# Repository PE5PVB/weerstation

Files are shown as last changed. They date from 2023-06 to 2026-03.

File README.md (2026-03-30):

# Weerstation



## Inleiding
Dit weerstation haalt alle weersinformatie voor jouw regio online op via een API van www.weerlive.nl. Jouw regio wordt bepaald aan de hand van de geografische coördinaten welke verkregen worden door de ingebouwde GPS ontvanger. Deze weersinformatie wordt elke 5 minuten vernieuwd. Mocht er een weerswaarschuwing gelden dan zal dit aangegeven worden met een rood knipperend uitroepteken. Druk op het uitroepteken om deze waarschuwing weer te geven. In dat zelfde scherm worden ook gedetecteerde bliksemontladingen weergegeven.
Voor radioamateurs is er ook een sectie ingericht waar relevante ruimteweersinformatie wordt weergegeven. Ook worden bandomstandigheden voor DX op korte golf en VHF getoond. Deze informatie wordt verkregen van hamqsl.com. De MUF informatie wordt verkregen van meteo.be. Deze gegevens worden respectievelijk elke 30 seconden en elke 20 seconden vernieuwd.
Tot slot is het weerstation uitgevoerd met een ingebouwde temperatuurmeter, luchtvochtigheidsmeter en een VOC meter. VOC geeft een indicatie van de luchtkwaliteit. VOC waardes onder 200 zijn prima, bij waardes boven 200 wordt ventilatie aanbevolen. Hoe hoger de waarde, hoe hoger de urgentie. Deze gegevens worden elke 5 seconden vernieuwd.
In een apart menu worden de GPS statistieken weergegeven. 

## Technische werking
Het hart van het weerstation is de ESP32 processor. Deze krachtige processor heeft ook een ingebouwd WiFi station. De software is geschreven op het welbekende Arduino platform. Software laden kan via de seriële poort J1. Hiervoor is wel een UART converter nodig. Om de ESP32 in de download stand te zetten dien je de spanning te verwijderen, de FLASH knop ingedrukt te houden en daarna de spanning terug te plaatsen. Hierna kun je de flash knop loslaten. Nu kun je de software laden.
Communicatie met de indoor temperatuur en luchtvochtigheid sensor loopt via een OneWire protocol. Dat wil zeggen dat alle data over één lijn loopt. Communicatie met de VOC en bliksemdetector loopt via de I2C databus. Tot slot is de GPS module gekoppeld middels een softwarematige seriële bus. 
Het Nextion display, dit is een HMI display wat dus zelfstandig werkt en dus ook eigen software heeft is aangesloten via de 2e seriële bus van de ESP32. Updates voor het Nextion scherm lopen via een SD kaart. Deze kan in de SD kaartlezer van het display worden geplaatst. Na het plaatsen dien je even kort de spanning los te halen. Daarna zal de update automatisch starten, de status wordt ook weergegeven op het display. Na de update kun je de SD kaart verwijderen en weer even kort de spanning los koppelen. Het display start daarna automatisch op met de nieuwe software.
De bliksemdetector analyseert ontvangen signalen op 500kHz met een bandbreedte van 33kHz. Aangezien dit vrij kritisch is, moet de capaciteit van de LC kring ingesteld worden voor een goede werking. Deze kan namelijk exemplarisch afwijken. In dit bouwproject wordt deze waarde automatisch gemeten en bepaald tijdens het opstarten.

## Handleiding
Dit weerstation is geheel afhankelijk van een werkende internet verbinding via Wi-Fi. Na het opstarten zal er eerst geprobeerd een verbinding te maken met het laatst verbonden Wi-Fi accesspoint. Mislukt dit, dan zal er een scherm verschijnen met de vraag om dit opnieuw te proberen. Druk je op het icoontje rechtsboven in het scherm, dan kun je eventueel de Wi-Fi opnieuw configureren.

### Wi-Fi opnieuw configureren
Je krijgt een QR code te zien. Ontgrendel je telefoon of tablet en scan de QR code. Je telefoon of tablet zal na een aantal seconden automatisch naar een configuratiepagina gaan waar je de Wi-Fi verbinding kunt configureren. Lukt dit niet, maak dan handmatig verbinding met het weerstation. De Wi-Fi-naam wordt onder de QR code getoond.

### API weerlive configureren
Zoals in de inleiding wordt geschreven maakt dit weerstation gebruik van de API van weerlive.nl. Het is dus belangrijk om een unieke code aan te vragen. Je kunt deze code gratis aanvragen door een account aan te maken op [https://weerlive.nl/api/toegang/](https://weerlive.nl/api/toegang/index.php). Let wel op, het aantal aanvragen per dag is voor de gratis accounts beperkt tot 300. Maak dus voor elk weerstation een unieke code aan. Je kunt de code invullen tijdens het configureren van Wi-Fi. 

## Hoofdscherm
In het hoofdscherm vind je de huidige weersinformatie, de weersverwachting en binnentemperatuur/luchtvochtigheid en VOC waarde. Daarnaast wordt boven in het scherm de plaats  getoond welke horen bij de getoonde weersinformatie. Mocht er voldoende GPS ontvangst zijn, of is NTP ingeschakeld, dan zal daar ook de actuele datum en tijd worden weergegeven én, indien Hamradio mode is geactiveerd, de 10 digit (Maidenhead) QTH locator.

## Hamradio scherm
In het Hamradio scherm worden de nodige data van de zonneactiviteit weergegeven, daarnaast worden de verwachte bandcondities voor de korte golf, de actuele Europese bandcondities voor VHF en de actuele MUF voor verschillende afstanden op de korte golf getoond. Dit laatste wordt als een ticker weergegeven onderin beeld.

## GPS scherm
Hier worden de actuele lengte- en breedtegraad, het aantal ontvangen satellieten, de actuele GPS UTC tijd, de berekende hoogte (niet nauwkeurig) en een foutindicatie weergegeven.

## Waarschuwingenscherm
In het waarschuwingenscherm worden actuele weerswaarschuwingen weergegeven met een ticker. Daarnaast wordt ook een lijst met laatst gedetecteerde bliksemontladingen getoond, hierbij wordt datum, tijd en relatieve afstand weergegeven.

## Configuratiescherm
De volgende gegevens kun je wijzigen in het configuratiescherm:

De eerste pagina bevat instellingen voor de bliksemdetector.

### Alleen bij weeralarm
Indien ingeschakeld worden er alleen blikseminslagen gedetecteerd indien er weer weerswaarschuwing van kracht is. Dit kan eventuele valse meldingen aanzienlijk reduceren.

### Bliksem gevoeligheid
Hiermee kun je de gevoeligheid van de bliksemdetector instellen. Een lagere waarde is gevoeliger, maar ook gevoeliger voor valse meldingen.

### Spike onderdrukking
Hiermee wordt de gevoeiligheid voor storingen ingesteld. Een lagere waarde is gevoeliger, maar ook gevoeliger voor valse meldingen.

### Binnen gebruik
Hiermee wordt de gevoeligheid van de detector geoptimaliseerd. Bij buiten gebruik zijn de omgevingsstoringen anders dan bij binnen gebruik. 

## Configuratie pagina 2:

### Beeper
Indien deze functie is ingeschakeld wordt er een pieptoon gegeven indien er een weerswaarschuwing geldt of indien er een bliksemontlading is gedetecteerd.

### Hamradio modus
Indien deze functie is ingeschakeld wordt het hamradio scherm toegankelijk en zal de QTH locatie bij voldoende GPS signaal worden getoond.

### Helderheid
Instelling voor helderheid van het scherm. Instelbaar tussen 20 en 100%.

### Km/u weergave
Geef de actuele windsnelheid in km/u. Indien uitgeschakeld is de weergave in m/s.

## Configuratie pagina 3:

### Auto locatie update
Indien ingeschakeld wordt de gedetecteerde GPS locatie gebruikt voor de weersinformatie. Indien het weerstation op een plek wordt geplaatst waar GPS ontvangst onmogelijk of zeer matig is, wordt aangeraden deze functie na één keer goede ontvangst uit te schakelen. Hierdoor wordt de informatie niet meer bijgewerkt. Dit is belangrijk omdat mogelijk foute data als gevolg van slechte ontvangst kan worden gebruikt. Indien dit is uitgeschakeld, zal de QTH locator ook niet meer worden weergegeven.

### Gebruik NTP
Vooral handig indien er slechte of geen GPS ontvangst mogelijk is. De datum en tijd wordt, indien geactiveerd, via het internet gesynchroniseerd.

### Indoor offset
Hiermee kun je de waarde van de temperatuursensor voor binnentemperatuur wijzigen. Dit is vooral van belang indien de temperatuursensor op de print wordt geplaatst. Eigen opgewekte warmte van het weerstation kunnen namelijk de gemeten temperatuur beïnvloeden. Het is aan te raden deze waarde te wijzigen wanneer het weerstation minimaal een uur is ingeschakeld.

### Auto dimmer
Indien ingeschakeld zal het display na 5 minuten automatisch gedimd worden. Dit kan ongedaan worden door het scherm aan te raken.

## Software
De software voor dit project is open source. Je kunt alle software en ook een 3d printbare behuizing vinden op mijn github pagina, https://github.com/PE5PVB/weerstation

Dit ontwerp is uitsluitend bedoeld voor zelfbouwtoepassing door hobbyisten. Commercieel gebruik en/of verkoop zonder toestemming van de auteur is nadrukkelijk niet toegestaan.

Aan de werking van software en/of hardware kunnen geen rechten worden ontleend. 
Bouw en gebruik is nadrukkelijk op eigen risico. 

De seriële poort van de ESP32 staat op de printplaat aangeduid met : G=Ground, T=TX, R=RX.

## Voeding

Dit weerstation wordt gevoed via een USB-C connector. Werkspanning is 5V. Het weerstation verbruikt maximaal 250mA. 

## Bouwinstructie

Ik heb dit project dusdanig ontworpen dat dit ook door niet ervaren zelfbouwers kan worden gebouwd. Het enige onderdeel waarmee je goed op moet letten is de ESP32 processor. Deze is namelijk  in SMD uitgevoerd. Begin altijd met het solderen van één aansluiting in een hoek. Je hebt dan namelijk de mogelijkheid om de ESP32 eventueel nog verder uit te lijnen. Weet je zeker dat de ESP32 goed is uitgelijnd, soldeer dan de andere hoek. Controleer nogmaals of de ESP32 goed is uitgelijnd en vlak op de printplaat ligt, daarna kun je de andere pootjes vast solderen.

Plaats nu vervolgens de overige onderdelen, begin bij laag (weerstanden) en eindig met hoog. Let bij het plaatsen van de transistor, de buzzer en elektrolytische condensatoren op de polariteit.

De bijgeleverde aansluitkabels van de DFRobot modules zijn vrij lang. Deze kun je naar eigen inzicht in te korten.
De aansluitingen van de kleuren van de draden van display en DFRobot modules staan aangegeven met de eerste letter van de kleur. (bv. R = Rood, B = Blauw, Z = zwart etc). Bij de bliksemdetector moet AUX worden aangesloten op de IRQ pin van het detector board. Dit is een losse pen! Bij de LED staat de L voor het lange pootje van de LED.

## Programmeren

Gebruik bij voorkeur de pre-compiled version van mijn github pagina. Start het programma FLASH.BAT en volg de instructies.
Indien je toch vanuit Arduino IDE wilt programmeren, controleer dan of alle benodigde libraries zijn geinstalleerd.

## Onderdelenlijst
Hieronder een overzicht van de benodigde componenten met componentennummer een aantal.

5x	C1, C2, C3, C5, C7		100n condensator (5mm pitch)

1x	C4				            100µF elektrolytische condensator (6.5mm diameter)

1x	C6				            10µF elektrolytische condensator (5.5mm diameter)

3x	R1, R2, R4			      10kΩ 0.25W weerstand

2x	R6, R7				        5.1kΩ 0.25W weerstand

1x	R3				            1kΩ 0.25W weerstand

1x	R5				            470Ω 0.25W weerstand

1x	D1				            3mm LED

1x	U1				            ESP32-WROOM-32UE

1x	U2				            DHT22 module

1x	U3				            LM1117T-3.3

1x	F1				            Zelfherstellende zekering PPTC Polyfuse 500mA (5mm pitch)

1x	SW1				            PCB Drukknop

1x	BZ1				            Actieve buzzer

1x	Q1				            BC547 transistor

1x	J1				            Pinheader, 3-pins (2.54mm pitch)

1x	J2				            ATGM336H GPS Module

1x	J3				            Pinheader, 4-pins (2.54mm pitch)

1x	J4				            DFRobot Gravity SGP40 module

1x	J5				            DFRobot Gravity Bliksem Afstandssensor

1x	J6				            USB-C 2.0 Female naar DIP Adapter

1x					              WiFi 2.4GHz antenne met uFL connector

1x					              Nextion Discovery 3.5” display

5x					              Bout M3 10mm

5x					              Moer M3

Alle bovenstaande onderdelen zijn verkrijgbaar bij Tinytronics.nl

## Trouble shooting

### Start niet goed op.
Mogelijk is de netadapter niet compatible. Ik heb dit project getest met een Raspberry Pi 4 voeding. Plaats eerst de USB kabel, daarna pas de adapter in de wandcontactdoos.

### Blijft tijdens het opstarten hangen op Bliksemdetector controle
Controleer of de AUX pin verbonden is met de IRQ pin van het detector board.

### Geeft geen actueel weerbericht, temperatuur blijft op 0 graden staan
Controleer API code op type fouten. Het is een hexadecimaal getal, dus gebruikte karakters zijn 0-9 en a-f.

### GPS module werkt niet
Controleer of de antenne connector niet tegen het batterijtje aan komt.

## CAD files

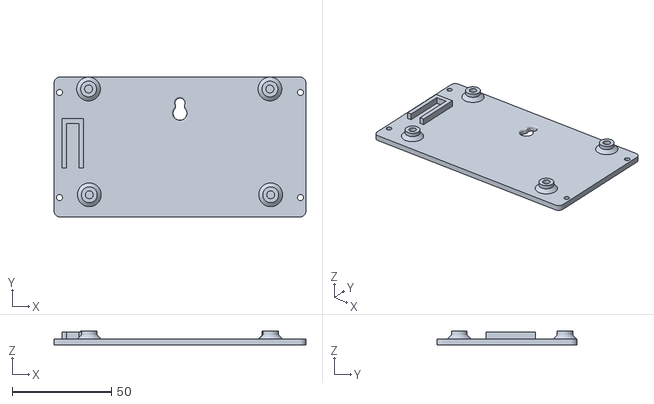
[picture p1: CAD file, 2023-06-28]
STL/mainboardback.stl
127.0 x 70.5 x 7.00

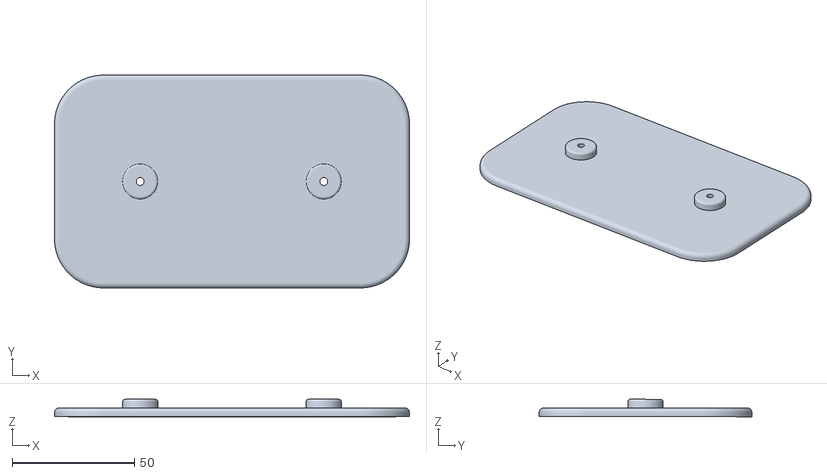
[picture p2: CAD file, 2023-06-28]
STL/foot.stl
145.0 x 86.9 x 7.17

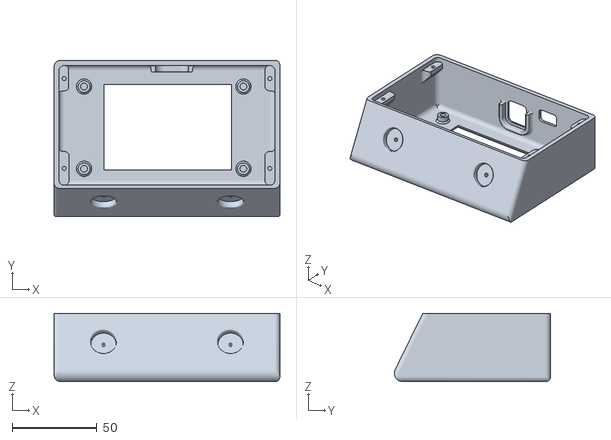
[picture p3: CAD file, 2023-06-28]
STL/frontcase.stl
133.4 x 92.3 x 40.3

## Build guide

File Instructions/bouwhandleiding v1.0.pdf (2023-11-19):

# Weerstation

### Bouwproject VRZA Radiokampweek 2023

## Inleiding

Dit weerstation haalt alle weersinformatie voor jouw regio online op via een API van www.weerlive.nl. Jouw regio wordt bepaald aan de hand van de geografische coördinaten welke verkregen worden door de ingebouwde GPS ontvanger. Deze weersinformatie wordt elke 5 minuten vernieuwd. Mocht er een weerswaarschuwing gelden dan zal dit aangegeven worden met een rood knipperend uitroepteken. Druk op het uitroepteken om deze waarschuwing weer te geven. In dat zelfde scherm worden ook gedetecteerde bliksemontladingen weergegeven.

Voor radioamateurs is er ook een sectie ingericht waar relevante ruimteweersinformatie wordt weergegeven. Ook worden bandomstandigheden voor DX op korte golf en VHF getoond. Deze informatie wordt verkregen van hamqsl.com. De MUF informatie wordt verkregen van meteo.be. Deze gegevens worden respectievelijk elke 30 seconden en elke 20 seconden vernieuwd.

Tot slot is het weerstation uitgevoerd met een ingebouwde temperatuurmeter, luchtvochtigheidsmeter en een VOC meter. VOC geeft een indicatie van de luchtkwaliteit. VOC waardes onder 200 zijn prima, bij waardes boven 200 wordt ventilatie aanbevolen. Hoe hoger de waarde, hoe hoger de urgentie. Deze gegevens worden elke 5 seconden vernieuwd.

In een apart menu worden de GPS statistieken weergegeven.

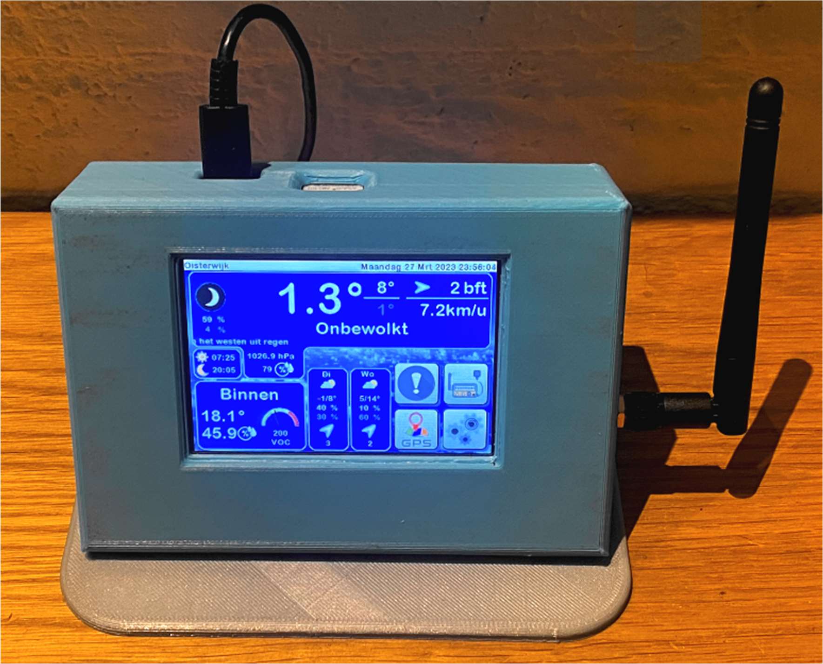
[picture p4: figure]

## Technische werking

Het hart van het weerstation is de ESP32 processor. Deze krachtige processor heeft ook een ingebouwd WiFi station. De software is geschreven op het welbekende Arduino platform. Software laden kan via de seriële poort J1. Hiervoor is wel een UART converter nodig. Om de ESP32 in de download stand te zetten dien je de spanning te verwijderen, de FLASH knop ingedrukt te houden en daarna de spanning terug te plaatsen. Hierna kun je de flash knop loslaten. Nu kun je de software laden.

Communicatie met de indoor temperatuur en luchtvochtigheid sensor loopt via een OneWire protocol. Dat wil zeggen dat alle data over één lijn loopt. Communicatie met de VOC en bliksemdetector loopt via de I2C databus. Tot slot is de GPS module gekoppeld middels een softwarematige seriële bus.

Het Nextion display, dit is een HMI display wat dus zelfstandig werkt en dus ook eigen software heeft is aangesloten via de 2e
seriële bus van de ESP32. Updates voor het Nextion scherm lopen via een SD kaart. Deze kan in de SD kaartlezer van het display worden geplaatst. Na het plaatsen dien je even kort de spanning los te halen. Daarna zal de update automatisch starten, de status wordt ook weergegeven op het display. Na de update kun je de SD kaart verwijderen en weer even kort de spanning los koppelen. Het display start daarna automatisch op met de nieuwe software.

De bliksemdetector analyseert ontvangen signalen op 500kHz met een bandbreedte van 33kHz. Aangezien dit vrij kritisch is, moet de capaciteit van de LC kring ingesteld worden voor een goede werking. Deze kan namelijk exemplarisch afwijken. In dit bouwproject wordt deze waarde automatisch gemeten en bepaald tijdens het opstarten.

## Handleiding

Dit weerstation is geheel afhankelijk van een werkende internet verbinding via Wi-Fi. Na het opstarten zal er eerst geprobeerd een verbinding te maken met het laatst verbonden Wi-Fi accesspoint. Mislukt dit, dan zal er een scherm verschijnen met de vraag om dit opnieuw te proberen. Druk je op het icoontje rechtsboven in het scherm, dan kun je eventueel de Wi-Fi opnieuw configureren.

Wi-Fi opnieuw configureren
Je krijgt een QR code te zien. Ontgrendel je telefoon of tablet en scan de QR code. Je telefoon of tablet zal na een aantal seconden automatisch naar een configuratiepagina gaan waar je de Wi-Fi verbinding kunt configureren. Lukt dit niet, maak dan handmatig verbinding met het weerstation. De Wi-Fi-naam wordt onder de QR code getoond.

API weerlive configureren
Zoals in de inleiding wordt geschreven maakt dit weerstation gebruik van de API van weerlive.nl. Het is dus belangrijk om een unieke code aan te vragen. Je kunt deze code gratis aanvragen door een account aan te maken op https://weerlive.nl/api/toegang/. Let wel op, het aantal aanvragen per dag is voor de gratis accounts beperkt tot 300. Maak dus voor elk weerstation een unieke code aan. Je kunt de code invullen tijdens het configureren van Wi-Fi.

Hoofdscherm
In het hoofdscherm vind je de huidige weersinformatie, de weersverwachting en binnentemperatuur/luchtvochtigheid en VOC waarde. Daarnaast wordt boven in het scherm de plaats getoond welke horen bij de getoonde weersinformatie. Mocht er voldoende GPS ontvangst zijn, of is NTP ingeschakeld, dan zal daar ook de actuele datum en tijd worden weergegeven én, indien Hamradio mode is geactiveerd, de 10 digit (Maidenhead) QTH locator.

Hamradio scherm
In het Hamradio scherm worden de nodige data van de zonneactiviteit weergegeven, daarnaast worden de verwachte bandcondities voor de korte golf, de actuele Europese bandcondities voor VHF en de actuele MUF voor verschillende afstanden op de korte golf getoond. Dit laatste wordt als een ticker weergegeven onderin beeld.

GPS scherm
Hier worden de actuele lengte- en breedtegraad, het aantal ontvangen satellieten, de actuele GPS UTC tijd, de berekende hoogte (niet nauwkeurig) en een foutindicatie weergegeven.

Waarschuwingenscherm
In het waarschuwingenscherm worden actuele weerswaarschuwingen weergegeven met een ticker. Daarnaast wordt ook een lijst met laatst gedetecteerde bliksemontladingen getoond, hierbij wordt datum, tijd en relatieve afstand weergegeven.

Configuratiescherm
De volgende gegevens kun je wijzigen in het configuratiescherm:

De eerste pagina bevat instellingen voor de bliksemdetector.

Alleen bij weeralarm
Indien ingeschakeld worden er alleen blikseminslagen gedetecteerd indien er weer weerswaarschuwing van kracht is. Dit kan eventuele valse meldingen aanzienlijk reduceren.

Bliksem gevoeligheid
Hiermee kun je de gevoeligheid van de bliksemdetector instellen. Een lagere waarde is gevoeliger, maar ook gevoeliger voor valse meldingen.

Spike onderdrukking
Hiermee wordt de gevoeiligheid voor storingen ingesteld. Een lagere waarde is gevoeliger, maar ook gevoeliger voor valse meldingen.

Binnen gebruik
Hiermee wordt de gevoeligheid van de detector geoptimaliseerd. Bij buiten gebruik zijn de omgevingsstoringen anders dan bij binnen gebruik.

Configuratie pagina 2:

Beeper
Indien deze functie is ingeschakeld wordt er een pieptoon gegeven indien er een weerswaarschuwing geldt of indien er een bliksemontlading is gedetecteerd.

Hamradio modus
Indien deze functie is ingeschakeld wordt het hamradio scherm toegankelijk en zal de QTH locatie bij voldoende GPS signaal worden getoond.

Helderheid
Instelling voor helderheid van het scherm. Instelbaar tussen 20 en 100%.

Km/u weergave
Geef de actuele windsnelheid in km/u. Indien uitgeschakeld is de weergave in m/s.

Configuratie pagina 3:

Auto locatie update
Indien ingeschakeld wordt de gedetecteerde GPS locatie gebruikt voor de weersinformatie. Indien het weerstation op een plek wordt geplaatst waar GPS ontvangst onmogelijk of zeer matig is, wordt aangeraden deze functie na één keer goede ontvangst uit te schakelen. Hierdoor wordt de informatie niet meer bijgewerkt. Dit is belangrijk omdat mogelijk foute data als gevolg van slechte ontvangst kan worden gebruikt. Indien dit is uitgeschakeld, zal de QTH locator ook niet meer worden weergegeven.

Gebruik NTP
Vooral handig indien er slechte of geen GPS ontvangst mogelijk is. De datum en tijd wordt, indien geactiveerd, via het internet gesynchroniseerd.

Indoor offset
Hiermee kun je de waarde van de temperatuursensor voor binnentemperatuur wijzigen. Dit is vooral van belang indien de temperatuursensor op de print wordt geplaatst. Eigen opgewekte warmte van het weerstation kunnen namelijk de gemeten temperatuur beïnvloeden. Het is aan te raden deze waarde te wijzigen wanneer het weerstation minimaal een uur is ingeschakeld.

Auto dimmer
Indien ingeschakeld zal het display na 5 minuten automatisch gedimd worden. Dit kan ongedaan worden door het scherm aan te raken.

## Software

De software voor dit project is open source. Je kunt alle software en ook een 3d printbare behuizing vinden op mijn github pagina, https://github.com/PE5PVB/weerstation (ontwerp behuizing, alle credits naar Eric-Jan de Boer)

Dit ontwerp is uitsluitend bedoeld voor zelfbouwtoepassing door hobbyisten. Commercieel gebruik en/of verkoop zonder toestemming van de auteur is nadrukkelijk niet toegestaan.

Aan de werking van software en/of hardware kunnen geen rechten worden ontleend. Bouw en gebruik is nadrukkelijk op eigen risico. De seriële poort van de ESP32 staat op de printplaat aangeduid met : G=Ground, T=TX, R=RX.

## Voeding

Dit weerstation wordt gevoed via een USB-C connector. Werkspanning is 5V. Het weerstation verbruikt maximaal 250mA.

## Bouwinstructie

Ik heb dit project dusdanig ontworpen dat dit ook door niet ervaren zelfbouwers kan worden gebouwd. Het enige onderdeel waarmee je goed op moet letten is de ESP32 processor. Deze is namelijk in SMD uitgevoerd. Begin altijd met het solderen van één aansluiting in een hoek. Je hebt dan namelijk de mogelijkheid om de ESP32 eventueel nog verder uit te lijnen. Weet je zeker dat de ESP32 goed is uitgelijnd, soldeer dan de andere hoek. Controleer nogmaals of de ESP32 goed is uitgelijnd en vlak op de printplaat ligt, daarna kun je de andere pootjes vast solderen.

Plaats nu vervolgens de overige onderdelen, begin bij laag (weerstanden) en eindig met hoog. Let bij het plaatsen van de transistor, de buzzer en elektrolytische condensatoren op de polariteit.

De bijgeleverde aansluitkabels van de DFRobot modules zijn vrij lang. Deze kun je naar eigen inzicht in te korten.

De aansluitingen van de kleuren van de draden van display en DFRobot modules staan aangegeven met de eerste letter van de kleur. (bv. R = Rood, B = Blauw, Z = zwart etc). Bij de bliksemdetector moet AUX worden aangesloten op de IRQ pin van het detector board. Dit is een losse pen! Bij de LED staat de L voor het lange pootje van de LED.

## Programmeren

Gebruik bij voorkeur de pre-compiled version van mijn github pagina. Start het programma FLASH.BAT en volg de instructies.

Indien je toch vanuit Arduino IDE wilt programmeren, controleer dan of alle benodigde libraries zijn geinstalleerd.

## Onderdelenlijst

Hieronder een overzicht van de benodigde componenten met componentennummer een aantal.

5x | C1, C2, C3, C5, C7 | 100n condensator (5mm pitch)
1x | C4 | 100µF elektrolytische condensator (6.5mm diameter)
1x | C6 | 10µF elektrolytische condensator (5.5mm diameter)
3x | R1, R2, R4 | 10kΩ 0.25W weerstand
2x | R6, R7 | 5.1kΩ 0.25W weerstand
1x | R3 | 1kΩ 0.25W weerstand
1x | R5 | 470Ω 0.25W weerstand
1x | D1 | 3mm LED
1x | U1 | ESP32-WROOM-32UE
1x | U2 | DHT22 module
1x | U3 | LM1117T-3.3
1x | F1 | Zelfherstellende zekering PPTC Polyfuse 500mA (5mm pitch)
1x | SW1 | PCB Drukknop
1x | BZ1 | Actieve buzzer
1x | Q1 | BC547 transistor
1x | J1 | Pinheader, 3-pins (2.54mm pitch)
1x | J2 | ATGM336H GPS Module
1x | J3 | Pinheader, 4-pins (2.54mm pitch)
1x | J4 | DFRobot Gravity SGP40 module
1x | J5 | DFRobot Gravity Bliksem Afstandssensor
1x | J6 | USB-C 2.0 Female naar DIP Adapter
1x | | WiFi 2.4GHz antenne met uFL connector
1x | | Nextion Discovery 3.5” display
5x | | Bout M3 10mm
5x | | Moer M3

Alle bovenstaande onderdelen zijn verkrijgbaar bij Tinytronics.nl

## Trouble shooting

Start niet goed op.
Mogelijk is de netadapter niet compatible. Ik heb dit project getest met een Raspberry Pi 4 voeding. Plaats eerst de USB kabel, daarna pas de adapter in de wandcontactdoos.

### Blijft tijdens het opstarten hangen op Bliksemdetector controle

Controleer of de AUX pin verbonden is met de IRQ pin van het detector board.

### Geeft geen actueel weerbericht, temperatuur blijft op 0 graden staan

Controleer API code op type fouten. Het is een hexadecimaal getal, dus gebruikte karakters zijn 0-9 en a-f.

### GPS module werkt niet

Controleer of de antenne connector niet tegen het batterijtje aan komt.

## Schema

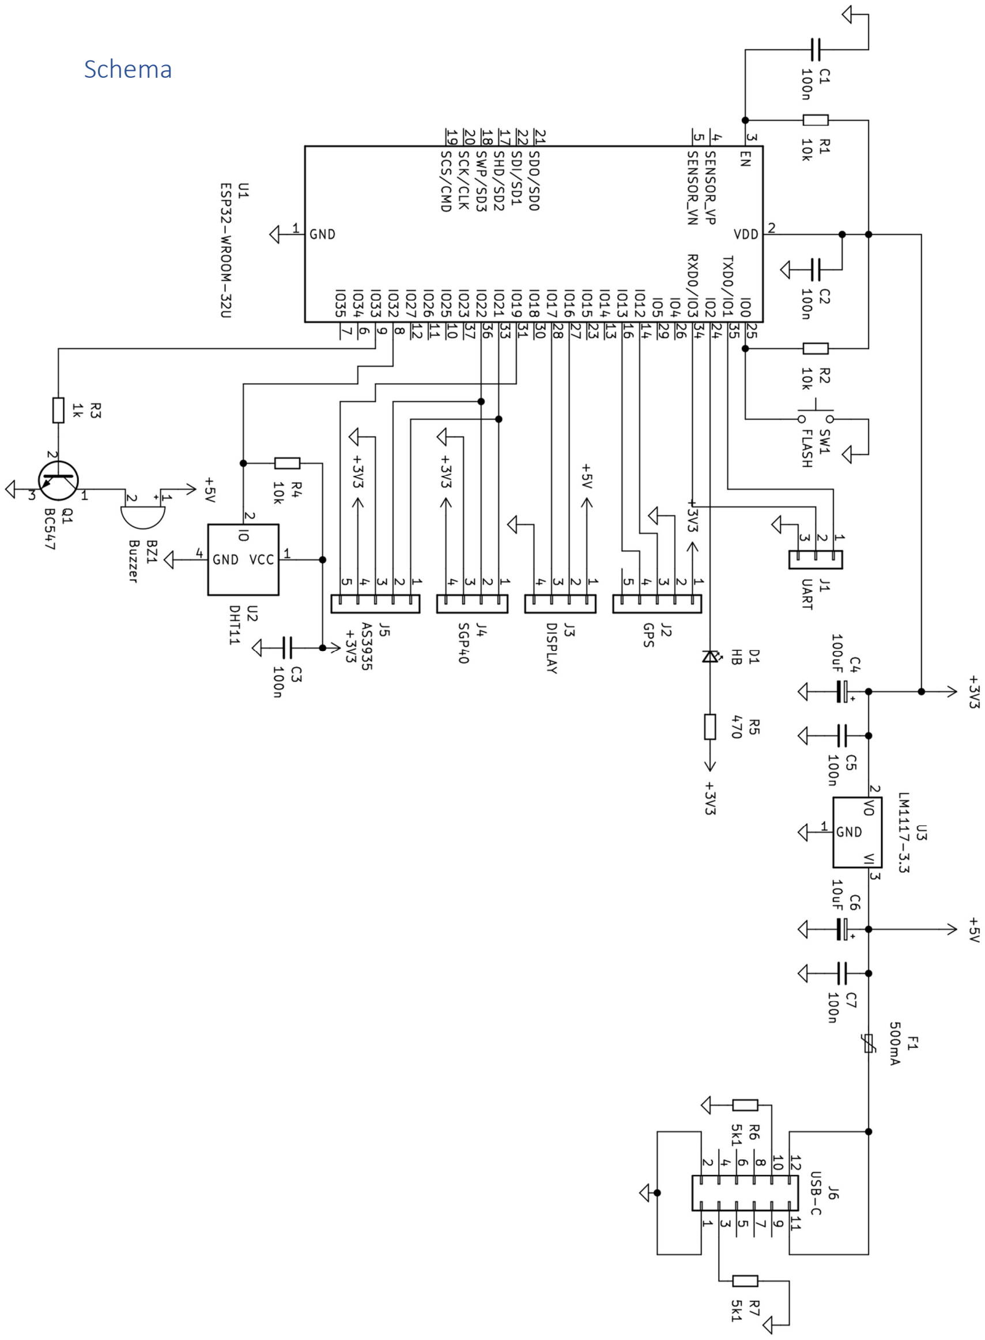
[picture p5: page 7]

## Componentenopstelling

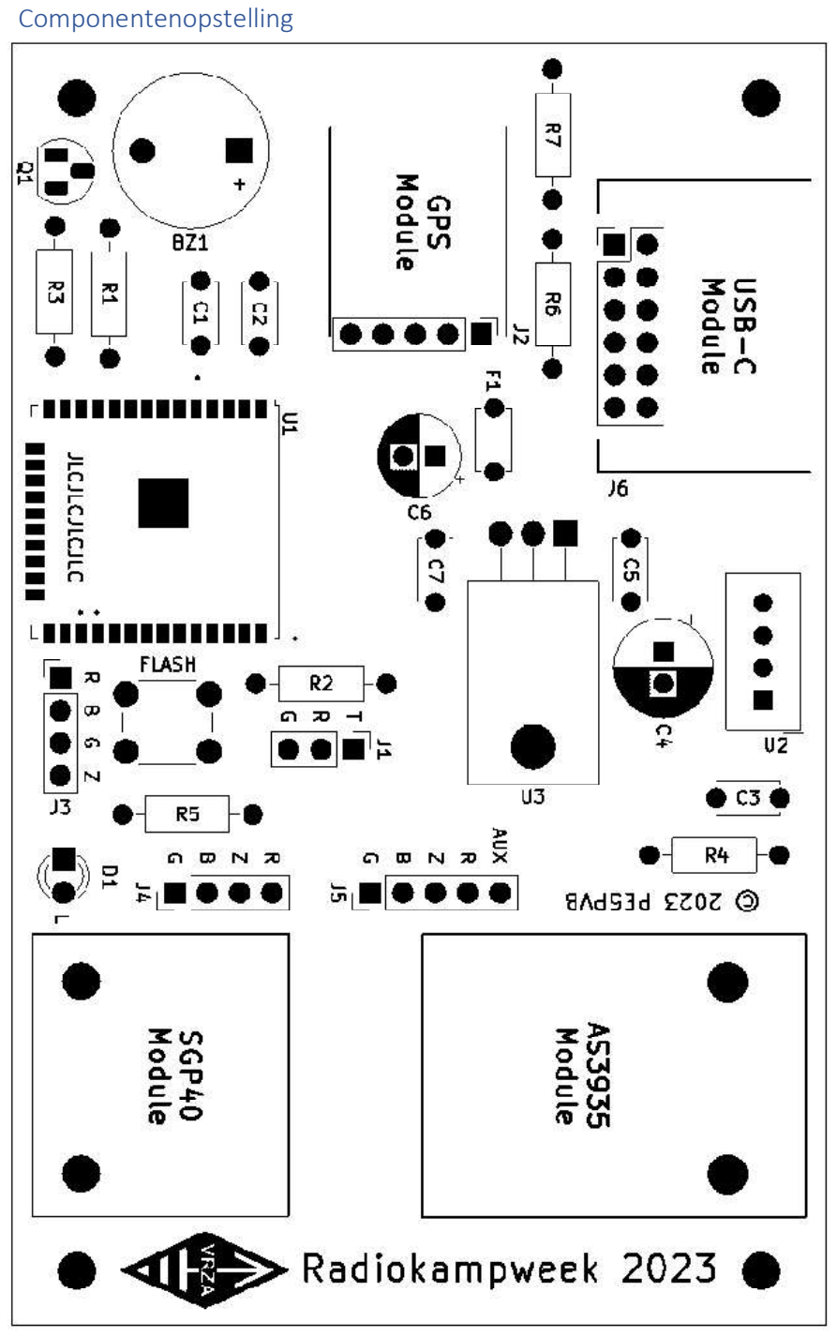
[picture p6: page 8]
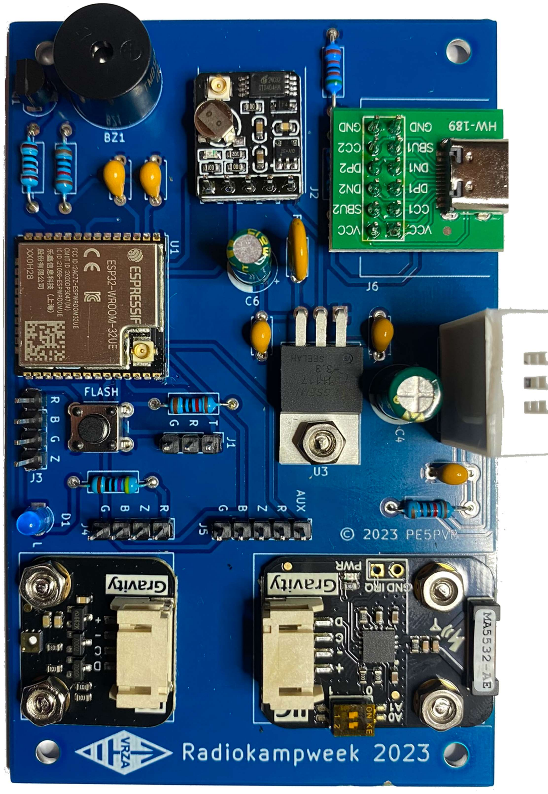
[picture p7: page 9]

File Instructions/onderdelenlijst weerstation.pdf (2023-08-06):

## De onderdelenlijst

Sommige onderdelen zijn lastig te vinden. Echter Tinytronics uit Eindhoven heeft vrijwel alles op voorraad !

Tinytronics levert desgewenst je ook een printplaat waarop reeds de ESP32 gesoldeerd is. Dat scheelt een boel priegelwerk. Om je het nog gemakkelijker te maken, kun je bij hen ook een volledige bouwkit met alle onderdelen bestellen. ( exclusief Kastje en USB voedingsadapter)

Zie verder op :
https://www.tinytronics.nl/shop/index.php?route=product/search&search=weerstation

Wil je het allemaal zelf doen, dan volgt hieronder de onderdelenlijst

Hierbij een overzicht van de benodigde componenten met componentennummer een aantal.

5x | C1, C2, C3, C5, C7 | 100n condensator (5mm pitch)
1x | C4 | 100µF elektrolytische condensator (6.5mm diameter)
1x | C6 | 10µF elektrolytische condensator (5.5mm diameter)
3x | R1, R2, R4 | 10kΩ 0.25W weerstand
2x | R6, R7 | 5.1kΩ 0.25W weerstand
1x | R3 | 1kΩ 0.25W weerstand
1x | R5 | 470Ω 0.25W weerstand
1x | D1 | 3mm LED
1x | U1 | ESP32-WROOM-32UE
1x | U2 | DHT22 module
1x | U3 | LM1117T-3.3
1x | F1 | Zelfherstellende zekering PPTC Polyfuse 500mA (5mm pitch)
1x | SW1 | PCB Drukknop
1x | BZ1 | Actieve buzzer
1x | Q1 | BC547 transistor
1x | J1 | Pinheader, 3-pins (2.54mm pitch)
1x | J2 | ATGM336H GPS Module
1x | J3 | Pinheader, 4-pins (2.54mm pitch)
1x | J4 | DFRobot Gravity SGP40 module
1x | J5 | DFRobot Gravity Bliksem Afstandssensor
1x | J6 | USB-C 2.0 Female naar DIP Adapter
1x | | WiFi 2.4GHz antenne met uFL connector
1x | | Nextion Discovery 3.5” display
5x | | Bout M3 10mm
5x | | Moer M3

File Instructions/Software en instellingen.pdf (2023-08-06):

## Software en instellingen

De software voor dit project is open source. Je kunt alle software en ook een 3d printbare behuizing ook vinden op de Github pagina van PE5PVB, https://github.com/PE5PVB/weerstation
(voor ontwerp behuizing, alle credits naar Eric-Jan de Boer).

Aan de werking van software en/of hardware kunnen geen rechten worden ontleend. Bouw en gebruik is nadrukkelijk op eigen risico.
Alle benodigde files vindt je in de ZIP file in de downloadmap, Software bijlage.
Pak de ZIP-file uit en schrijf alles naar een aparte map op je PC of laptop.

### Update Nextion grafisch display

Het Nextion display, dit is een Human Machine Interface (HMI) display wat zelfstandig werkt en dus ook eigen software heeft, en is aangesloten via de 2e
seriële bus van de ESP32. Updates voor het Nextion scherm lopen via een SD kaart. Gebruik een goed merk 16 Gb Micro SD kaartje

Op het SD kaartje dient eerst nog 1 bestand te worden gezet :
- weerstation.tft

De SD kaart kan dan in de SD kaartlezer van het display worden geplaatst.
Na het plaatsen dien je de spanning aan te sluiten. Daarna zal de update automatisch starten, de status wordt ook weergegeven op het display.
Na de update kun je de spanning uit te schakelen en de SD kaart verwijderen.
Na het weer inschakelen tart het display dan automatisch op met de nieuwe software.

## Het programmeren van de ESP32

Gebruik bij voorkeur het pre-compiled version FLASH.BAT bestand in de Software bijlage. Dit is de snelste en de meest gemakkelijke manier om alles te laden.

Software laden kan via de seriële poort J1. Hiervoor is wel een UART converter nodig.

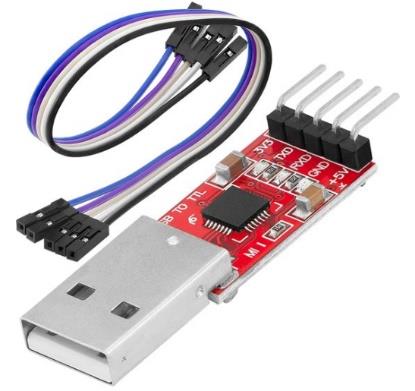
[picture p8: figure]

Stop de UART convertor in een USB poort op je laptop of PC en controleer welke COM-poort er wordt toegevoegd !
De seriële poort van de ESP32 staat op de printplaat aangeduid met : G=Ground, T=TX, R=RX. Verbind TX van de print met RX van de UART convertor en RX van de print met TX. G met Ground.

Start het FLASH.BAT bestand via je PC of Laptop op

Om de ESP32 in de download stand te zetten dien je de spanning te verwijderen, de FLASH knop op de print ingedrukt te houden en daarna de spanning terug te plaatsen op de USB ingang.
Hierna kun je de flash knop loslaten. De ESP32 komt hiermede in de laad-modus.

Nu kun je de software laden. Druk op <Enter> in je PC of Laptop en volg de aanwijzingen op het scherm om het laden te starten.

Opmerking :
Indien je toch vanuit Arduino IDE wilt programmeren, controleer dan of alle benodigde libraries zijn geïnstalleerd en gebruik het weerstation.ino bestand.

Na het laden verwijder je de voedingspanning en de aansluitingen van de UART.
Daarna kun je de voedingspanning weer aanbrengen.

### Let op :

Bij de bliksemdetector moet AUX worden aangesloten op de IRQ pin van het detector board met een los draadje. Vergeet dat niet !!

## Opstarten Weerstation

Het weerstation is geheel afhankelijk van een goed werkende internet verbinding via Wi-Fi.
Na het opstarten zal er eerst geprobeerd een verbinding te maken met het laatst verbonden Wi-Fi accesspoint. Mislukt dit, dan zal er een scherm verschijnen met de vraag om dit opnieuw te proberen. Druk je op het icoontje rechtsboven in het scherm, dan kun je de Wi-Fi opnieuw configureren. ( Opmerking : dit zal dus ook de eerste keer het geval zijn)

Wi-Fi opnieuw configureren
Je krijgt een QR code te zien. Ontgrendel je telefoon of tablet en scan de QR code. Je telefoon of tablet zal na een aantal seconden automatisch naar een configuratiepagina gaan waar je de Wi-Fi verbinding kunt configureren. Lukt dit niet, maak dan handmatig verbinding met het weerstation. De Wi-Fi-naam wordt onder de QR code getoond.
Bij het instellen heb je nu ook je API code nodig. Zorg dus dat je die bij de hand hebt.

Bij een goed gevonden Wifi signaal zal het weerstation nu opstarten.
Heb je een goede GPS dekking dan zal je huidige locatie worden getoond en de bijbehorende QTH locator gegevens, Indien je geen of een te zwak GPS aanwezig is, schakel dan de NTP instelling in het configuratiescherm in, om de juiste datum en tijd te krijgen.

### Trouble Shooting

Start niet goed op.
Mogelijk is de netadapter niet compatible. Ik heb dit project getest met een Raspberry Pi 4 voeding. Plaats eerst de USB kabel, daarna pas de adapter in de wandcontactdoos.

### Blijft tijdens het opstarten hangen op Bliksemdetector controle

Controleer of de AUX pin verbonden is met de IRQ pin van het detector board.

### Geeft geen actueel weerbericht, temperatuur blijft op 0 graden staan

Controleer API code op type fouten. Het is een hexadecimaal getal, dus gebruikte karakters zijn 0-9 en a-f.

### GPS module werkt niet

Controleer of de antenne connector niet tegen het batterijtje aan komt.

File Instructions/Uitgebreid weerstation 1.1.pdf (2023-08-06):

# Uitgebreid weerstation PE5PVB

Door Cor Struyk PA0GTB

### Inleiding

Soms valt je oog op een mooi project waarvan je gelijk weet, dat wil ik ook gaan maken. Dat gebeurde ook toen ik onlangs terugkwam van vakantie en een heel mooi artikel vond van Sjef Verhoeven PE5PVB. Het betrof een uitgebreid weerstation dat hij als bouwproject voor de VRZA-kampweek 2023 had gemaakt.

Via Github vond ik de Gerberfiles voor de printplaat, en toen ik hierover mijn vaste bouwmaatje Bert PA1BM, benaderde waren we het er gelijk over eens: dit werd ons volgende project.

Onlangs hebben we het project succesvol afgerond en heb ik Sjef PE5PVB benaderd of ik dit mooie project apart mocht beschrijven. Sjef gaf mij toestemming en info verstrekt zodat ik dit project hier nu nader beschrijf.

### Algemeen

Dit weerstation haalt alle weersinformatie voor jouw regio online op via een API van www.weerlive.nl. Jouw regio wordt bepaald aan de hand van de geografische coördinaten door de ingebouwde GPS-ontvanger. Deze weersinformatie wordt elke vijf minuten vernieuwd.

Mocht er een weerswaarschuwing gelden zie je dat meteen aan het rode uitroepteken. Druk op dit uitroepteken om deze waarschuwing weer te geven. In dat zelfde scherm worden ook gedetecteerde bliksemontladingen weergegeven.

Voor radioamateurs is er ook een sectie ingericht met relevante propagatieinformatie. Ook worden bandomstandigheden voor DX op korte golf en VHF getoond. Deze informatie komt van hamqsl.com. De MUF-informatie wordt verkregen van meteo.be. Deze gegevens worden respectievelijk elke 30 seconden en elke 20 seconden vernieuwd.

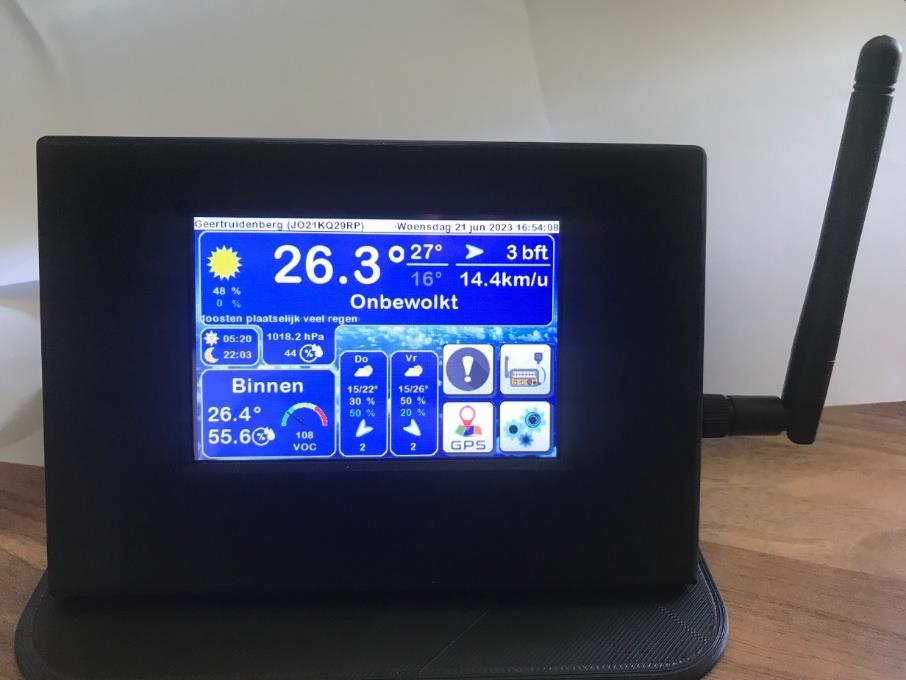
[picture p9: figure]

Het weerstation is voorzien van een aantal sensoren zodat je in een oogopslag kunt zien hoe het er binnen en buiten bijstaat. Te onderkennen zijn:

- Actuele weerinformatie van jou regio via Weeronline.nl
- Regionale KNMI weeralarm situatie voor jou regio
- Weersverwachting komende dagen
- Indoor temperatuur en vochtigheidssensor
- Windrichting en snelheden
- VOC-sensor (Luchtkwaliteit)
- GPS-sensor met antenne ( bepaalt je plaats en QTH locator)
- NTP datum en tijd (optioneel in te schakelen)
- Bliksemdetector

### Ham Radio mode

Naast de actuele indoor- en outdoor weerindicatie is het ook mogelijk om een zogenaamde. Hamradio mode in te schakelen. Hierbij wordt je 10 digit (Maidenhead) QTH locator getoond. In het Hamradioscherm worden de nodige data van de zonneactiviteit weergegeven. Daarnaast worden de verwachte bandcondities voor de korte golf, de actuele Europese bandcondities voor VHF en de actuele MUF voor verschillende afstanden op de korte golf getoond.

### De gebruikte techniek

Het hart van het weerstation is de ESP32 processor. Deze krachtige processor heeft ook een ingebouwd WiFi-station. De software is geschreven op het welbekende Arduino-platform. Software laden kan via de seriële poort J1. Hiervoor is wel een UART converter nodig.

Om de ESP32 in de downloadstand te zetten moet je de spanning verwijderen, de FLASH knop ingedrukt houden en daarna de spanning terugplaatsen. Hierna kun je de flash-knop loslaten. Nu kun je de software laden.

Communicatie met de indoor temperatuur en luchtvochtigheidssensor loopt via een OneWire-protocol. Dat wil zeggen dat alle data over één lijn loopt. Communicatie met de VOC en bliksemdetector loopt via de I2C databus. Tot slot is de GPS-module gekoppeld middels een softwarematige seriële bus.

Er wordt gebruikgemaakt van een Nextion grafisch display met touch screenbediening. Voorafgaand aan het programmeren van de ESP32 moet het display eerst geüpdatet worden via een SD-kaart. Zie hiervoor de softwarehandleiding waarin beschreven staat hoe dit te doen.

De bliksemdetector analyseert ontvangen signalen op 500kHz met een bandbreedte van 33kHz. Aangezien dit vrij kritisch is, moet de capaciteit van de LC-kring ingesteld worden voor een goede werking. Deze kan namelijk exemplarisch afwijken. In dit bouwproject wordt deze waarde automatisch gemeten en bepaald tijdens het opstarten.

### Internetverbinding

Dit weerstation is geheel afhankelijk van een werkende internetverbinding via Wi-Fi. Na het opstarten probeert het apparaat een verbinding te maken met het laatst verbonden Wi-Fi accesspoint. Mislukt dit, dan zal er een scherm verschijnen met de vraag om dit opnieuw te proberen. Druk je op het icoontje rechtsboven in het scherm, dan kun je de Wi-Fi opnieuw configureren.

Wi-Fi opnieuw configureren

Je krijgt een QR-code te zien. Ontgrendel je telefoon of tablet en scan de QR-code. Je telefoon of tablet zal na een aantal seconden automatisch naar een configuratiepagina gaan waar je de Wifi verbinding kunt configureren.

Lukt dit niet, maak dan handmatig verbinding met het weerstation. De Wi-Finaam wordt onder de QR-code getoond. Zie voor meer details de softwarehandleiding.

### API-code Weerlive.nl

Dit weerstation maakt gebruik van de API van weerlive.nl. Het is dus belangrijk om een unieke code aan te vragen. Je kunt deze gratis aanvragen door een account aan te maken op https://weerlive.nl/api/toegang/. Maak voor elk weerstation een unieke code aan. Je kunt de API-code invullen tijdens het configureren van Wi-Fi.

### Het schema

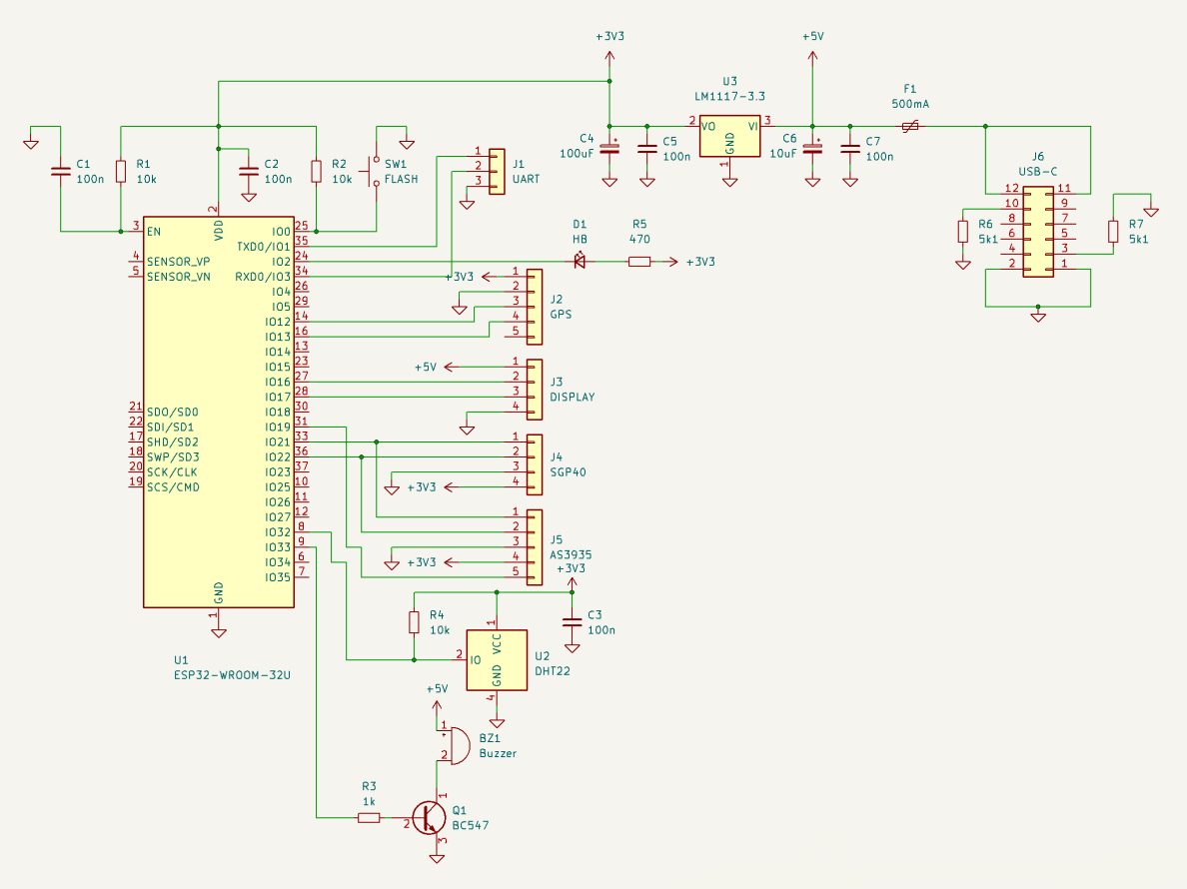
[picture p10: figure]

### De bouwinstructie

Sjef heeft dit project dusdanig ontworpen dat ook niet- ervaren zelfbouwers dit kunnen maken. Het enige onderdeel waarmee je goed moet opletten is de ESP32-processor. Deze is namelijk in SMD uitgevoerd.

Begin altijd met het solderen van één aansluiting in een hoek. Je hebt dan namelijk de mogelijkheid om de ESP32 eventueel nog verder uit te lijnen. Weet je zeker dat de ESP32 goed is uitgelijnd, soldeer dan de andere hoek. Controleer nogmaals of de ESP32 goed is uitgelijnd en vlak op de printplaat ligt. Daarna kun je de andere pootjes vastsolderen.

Plaats nu vervolgens de overige onderdelen, begin bij laag (weerstanden) en eindig met hoog. Let bij het plaatsen van de transistor, de buzzer en elektrolytische condensatoren op de polariteit.

De bijgeleverde aansluitkabels van de DFRobot-modules zijn vrij lang. Deze kun je naar eigen inzicht inkorten. De aansluitingen van de kleuren van de draden van display en DFRobot-modules staan aangegeven met de eerste letter van de kleur. (bv. R = Rood, B = Blauw, Z = zwart etc).

Bij de bliksemdetector moet AUX worden aangesloten op de IRQ-pin van het detector board. Dit is een losse pen! Bij de LED staat de L voor het lange pootje van de LED.

### De afgewerkte print

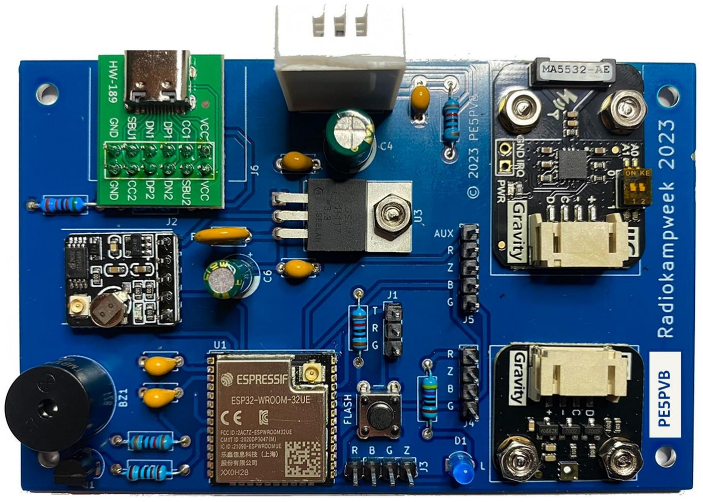
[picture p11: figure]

### Beschikbaarheid printplaat

Om het allemaal gemakkelijker te maken, levert Tinytronics de printplaat met reeds gesoldeerde ESP32-processor. Dat scheelt een hoop werk. Er zijn ook complete bouwkits met alle onderdelen (exclusief kastje en voeding) leverbaar. Wil je het helemaal zelf doen, dan vindt je de Gerber-files in de downloadfolder.

### Bijlagen

Op de Github site vind je een aantal bijlagen die nader ingaan op de aanpak en werkwijze, het programmeren, beschrijving van de verschillende schermen, beschikbaarheid van de software, de onderdelenlijst en eventuele trouble shooting.

Ook zijn hier de Gerberfiles voor de printplaat en informatie voor een te printen 3D kastje beschikbaar.

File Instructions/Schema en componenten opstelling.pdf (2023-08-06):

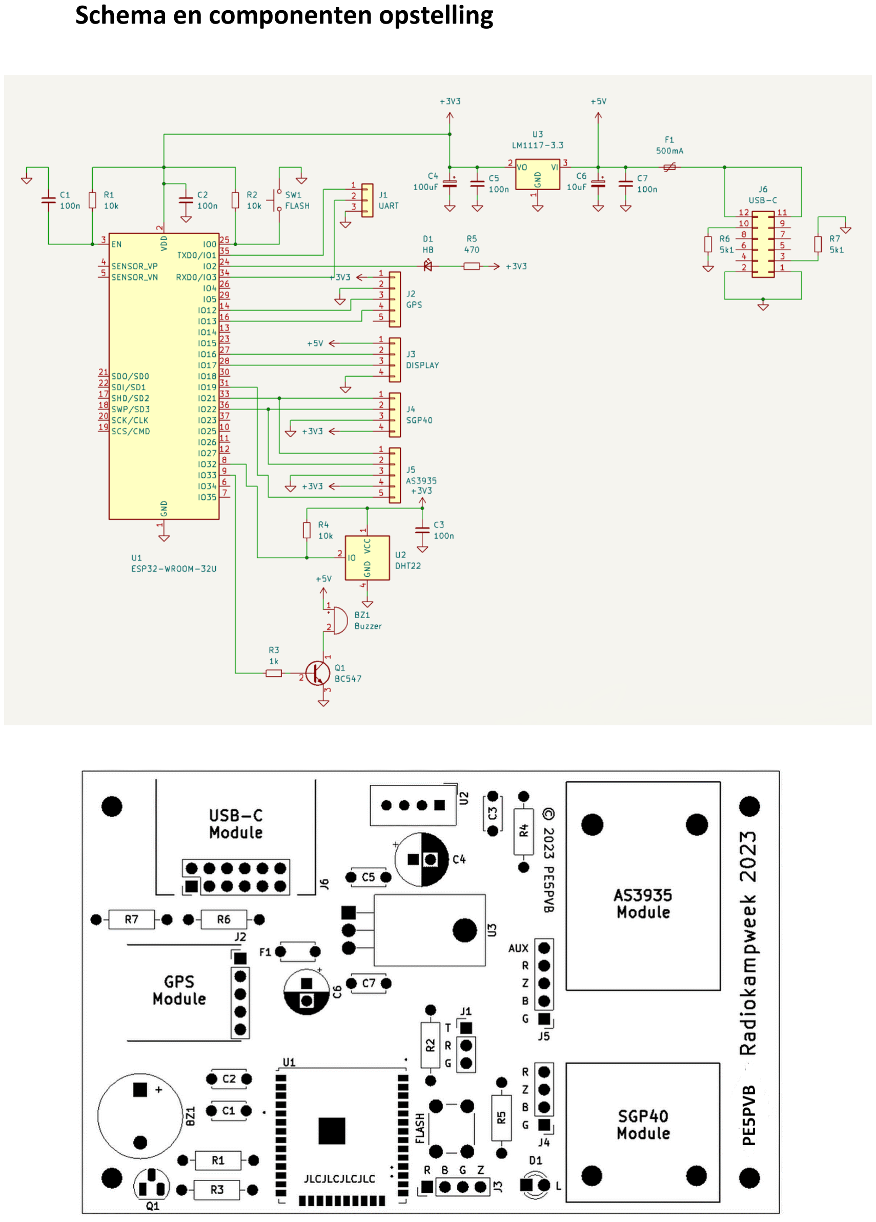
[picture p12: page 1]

Schema en componenten opstelling

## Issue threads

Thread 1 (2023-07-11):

Naar net buitenland.

Bandjeplak, 2023-07-11:
Heb het weerstation meegenomen op vakantie in Duitsland. Station krijgt wel een gps fix > locator verschijnt, maar er komt geen plaats in het display te staan. Nu krijgt het station geen lokale weer info van weerlive. ( werkt wel als je plaats invult in de url ( https://weerlive.nl/api/json-data-10min.php?key=eigenapi&locatie=Reit%20im%20Winkl ).

PE5PVB, 2023-07-11:
Klopt. Weerlive werkt alleen met geografische coördinaten binnen Nederland. Dit project is ook bedoeld voor gebruik binnen Nederland.

Closed 2023-07-11.

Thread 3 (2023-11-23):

V1.3 blijft hangen

Bandjeplak, 2023-11-23:
Na update van display en ESP blijft het geheel hangen op Lightning sensor OK. Ook na nieuwe flash en resets.

PE5PVB, 2023-11-23:
Dat is waarschijnlijk het AUX draadje los.

Bandjeplak, 2023-11-23:
Dat klopt, hij zat er net aan tegenaan, nu vastgezet en hij start weer door. Dank voor de snelle reactie.

Closed 2023-11-23.

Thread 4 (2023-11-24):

Groter display

Bandjeplak, 2023-11-24:
Is het mogelijk dat het display niet alleen in 3.5 maar ook in grotere formaten gemaakt kan worden. Voor oudere mensen of mensen die slecht kunnen zien is dit display echt te klein. Denk aan 7", 8" en zelfs 10"

PE5PVB, 2023-11-24:
Hi,

Je kunt een grotere variant van Nextion kopen, die zijn echter best prijzig. De .HMI is te downloaden op Github, daar kun je wijzigingen doorvoeren om het passend op de resolutie te maken. Ik ga dat niet doen omdat dit best veel werk is.

PE5PVB, 2023-11-24:
Ik heb op google gewoon gezocht naar plaatjes welke passen bij het weerbeeld.
Zal het even open laten staan voor je.

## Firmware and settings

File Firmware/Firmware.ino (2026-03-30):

#include <WiFiClient.h>
#include <WiFiClientSecure.h>
#include <HTTPClient.h>
#include <HTTPUpdate.h>
#include <EEPROM.h>
#include <esp_task_wdt.h>
#include "src/AS3935_ESP32.h"
#include "src/maidenhead.h"
#include "src/WiFiConnect.h"
#include <ArduinoJson.h>                        // https://github.com/bblanchon/ArduinoJson
#include <TinyGPS++.h>                          // https://github.com/mikalhart/TinyGPSPlus
#include <SoftwareSerial.h>                     // https://github.com/plerup/espsoftwareserial
#include <DFRobot_SGP40.h>                      // https://github.com/DFRobot/DFRobot_SGP40
#include "DHT.h"                                // https://github.com/adafruit/DHT-sensor-library
#include <EasyNextionLibrary.h>                 // https://github.com/Seithan/EasyNextionLibrary

#define SOFTWAREVERSION 16

// Nederlandse tijdzone: CET (UTC+1) met zomertijd CEST (UTC+2)
// M3.5.0/2 = laatste zondag maart om 02:00, M10.5.0/3 = laatste zondag oktober om 03:00
#define NL_TIMEZONE "CET-1CEST,M3.5.0/2,M10.5.0/3"

WiFiConnect wc;
TinyGPSPlus gps;
EasyNex Display(Serial2);
DHT dht(32, DHT22);
SoftwareSerial ss(12, 13);
DFRobot_SGP40 mySgp40;
AS3935_ESP32 lightning(AS3935_ADDR_DEFAULT);

bool beeper;
bool beeper_alarm = false;
bool beeper_lightning = false;
bool display_alarm = false;
bool display_gps = false;
bool display_radio = false;
bool display_weather = true;
bool menu;
bool radio;
bool weeralarm;
bool weeralarmold;
bool wifistatus = false;
byte alarmswitch;
byte autodim;
byte autoloc;
byte contrast = 100;
byte currenttrigger;
byte d1image;
byte d1imageold;
byte d1windk;
byte d1windkold;
byte d2image;
byte d2imageold;
byte d2windk;
byte d2windkold;
byte image;
byte imageold;
byte indoor;
int indooroffset;
int dauw;
int dauwold;
byte lv;
byte lvold;
byte ntp;
byte spike;
byte threshold;
long rssiold;
byte winds;
byte windsold;
int zicht;
int zichtold;
byte kmu;
double latitude;
double longitude;
int br_mmpu[24];
char br_tijd[24][6];
int d0tmax;
int d0tmaxold;
int d0tmin;
int d0tminold;
int d1neerslag;
int d1neerslagold;
int d1tmax;
int d1tmaxold;
int d1tmin;
int d1tminold;
int d1zon;
int d1zonold;
int d2neerslag;
int d2neerslagold;
int d2tmax;
int d2tmaxold;
int d2tmin;
int d2tminold;
int d2zon;
int d2zonold;
int indoorhum;
int indoorhumold;
int indoortemp;
int indoortempold;
int indoorvoc;
int indoorvocold;
int lightningcount = -1;
int luchtd;
int luchtdold;
int temp;
int tempold;
int windkmh;
int windkmhold;
int windms;
int windmsold;
String aindex;
String aindexold;
String alarmtxt;
String alarmtxtold = "Dummy";
String aurora;
String auroraold;
String br_tijdold;
String d1210m;
String d1210mold;
String d1715m;
String d1715mold;
String d1windr;
String d1windrold;
String d2windr;
String d2windrold;
String d3020m;
String d3020mold;
String d8040m;
String d8040mold;
String datetime;
String datetimeold;
String datetimestamp;
String dayname1old;
String dayname2old;
String electonflux;
String electonfluxold;
String es2m;
String es2mold;
String es4m;
String es4mold;
String es6m;
String es6mold;
String geomagfield;
String geomagfieldold;
String key;
String kindex;
String kindexold;
String latdegree;
String latdegreeold;
String latitudeold;
String lightningtext[6];
String lightningtextmerge = "Geen meldingen";
String lightningtextmergeold;
String longitudeold;
String magneticfield;
String magneticfieldold;
String muf_string[9];
String muf_stringold[9];
String n1210m;
String n1210mold;
String n1715m;
String n1715mold;
String n3020m;
String n3020mold;
String n8040m;
String n8040mold;
String normalisation;
String normalisationold;
String plaats;
String plaatsold;
String protonflux;
String protonfluxold;
String qthold;
String samenv;
String samenvold;
String signalnoise;
String signalnoiseold;
String solarflux;
String solarfluxold;
String solarwind;
String solarwindold;
String sunspots;
String sunspotsold;
String verw;
String verwold;
String weercode;
String weercodeold;
String windr;
String windrold;
String zononder;
String zononderold;
String zonop;
String zonopold;
unsigned long time_1 = 0;
unsigned long time_2 = 0;
unsigned long time_3 = 0;
unsigned long time_4 = 0;
unsigned long time_5 = 0;
unsigned long time_6 = 0;
const int intPin = 19;

void setup(void) {
  pinMode(2, OUTPUT);
  pinMode(33, OUTPUT);
  pinMode(intPin, INPUT);
  ss.begin(9600);
  Display.begin(115200);
  Serial.begin(115200);
  EEPROM.begin(47);
  if (EEPROM.readByte(41) != 11) defaults();
  latitude = EEPROM.readDouble(9);
  longitude = EEPROM.readDouble(1);
  key = EEPROM.readString(17);
  beeper = EEPROM.readByte(29);
  radio = EEPROM.readByte(30);
  kmu = EEPROM.readByte(32);
  autoloc = EEPROM.readByte(33);
  indoor = EEPROM.readByte(34);
  threshold = EEPROM.readByte(35);
  autodim = EEPROM.readByte(36);
  contrast = EEPROM.readByte(37);
  spike = EEPROM.readByte(38);
  alarmswitch = EEPROM.readByte(39);
  ntp = EEPROM.readByte(40);
  indooroffset = EEPROM.readInt(42);
  Display.writeNum("dim", contrast);
  buzzer(0);
  Display.writeStr("page 0");
  Display.writeNum("tm0.en", 0);
  Display.writeStr("version.txt", ("v " + String(SOFTWAREVERSION / 10) + "." + String(SOFTWAREVERSION % 10)));

  // Lightning sensor EERST calibreren, vóór WiFi (WiFi-radio verstoort de AS3935)
  Wire.begin();
  Display.writeStr("info.txt", "Lightning sensor");
  Display.writeStr("status.txt", " ");
  if (!lightning.begin(intPin)) {
    Serial.println("Geen Lightning sensor");
    Display.writeStr("status.txt", "FOUT!");
  } else {
    Serial.println("Lightning sensor OK");
    Display.writeStr("status.txt", "OK!");
    AS3935_TuneResult tune = lightning.tuneAntenna();
    if (!tune.success) {
      Serial.println("Antenne calibratie mislukt!");
    }
    setLightning();
  }
  delay(1000);

  // WiFi verbinding opbouwen (na lightning calibratie)
  Display.writeStr("info.txt", "Verbinden met WiFi...");
  Display.writeStr("status.txt", " ");
  Serial.print("WiFi verbinding opbouwen.....");
  if (wc.autoConnect()) {
    Serial.println("WiFi verbonden");
    Display.writeStr("status.txt", "OK!");
    wifistatus = true;
  } else {
    Serial.println("Geen verbinding, opnieuw instellen");
    Display.writeStr("page 6");
    while (!wifistatus) Display.NextionListen();
    Display.writeStr("page 0");
  }
  delay(1000);
  Display.writeStr("info.txt", "GPS module");
  Display.writeStr("status.txt", " ");
  if (!ss.available()) {
    Serial.println("Geen GPS module");
    Display.writeStr("status.txt", "FOUT!");
  } else {
    Serial.println("GPS module OK");
    Display.writeStr("status.txt", "OK!");
  }
  delay(1000);
  Display.writeStr("info.txt", "Temperatuur sensor");
  Display.writeStr("status.txt", " ");
  dht.begin();
  if (isnan(dht.readTemperature())) {
    Serial.println("Geen temperatuur sensor");
    Display.writeStr("status.txt", "FOUT!");
  } else {
    Serial.println("Temperatuursensor OK");
    Display.writeStr("status.txt", "OK!");
  }
  delay(1000);
  Display.writeStr("info.txt", "VOC sensor");
  Display.writeStr("status.txt", " ");
  if (!mySgp40.begin(10000)) {
    Serial.println("Geen VOC sensor");
    Display.writeStr("status.txt", "FOUT!");
  } else {
    Serial.println("VOC sensor OK");
    Display.writeStr("status.txt", "OK!");
  }
  delay(1000);
  if (radio == 1) Display.writeNum("radiobutton", 1);
  Serial.println("Setup klaar");
  Display.writeStr("info.txt", "Gegevens downloaden...");
  Display.writeStr("status.txt", " ");
  getWeather();
  getIndoor();
  showRSSI();
  delay(1000);
  configTzTime(NL_TIMEZONE, "europe.pool.ntp.org");
  Display.writeNum("setkmu", kmu);
  Display.writeStr("page 1");
  showData();
  buienradar();

  // Watchdog timer: herstart ESP32 als loop() langer dan 30s blokkeert
  esp_task_wdt_init(30, true);
  esp_task_wdt_add(NULL);
}

void loop(void) {
  esp_task_wdt_reset();
  digitalWrite(2, HIGH);
  Display.NextionListen();
  getGPS();

  if (!menu) {
    if (millis() - time_1 >= 600000) {   // 10 minuten (hamqsl.com update ~15 min)
      time_1 = millis();
      getPropagation();
    }

    if (millis() - time_2 >= 600000) {   // 10 minuten (MUF data update per kwartier)
      time_2 = millis();
      getMUF();
    }

    if (millis() - time_3 >= 300000) {   // 5 minuten
      time_3 = millis();
      getWeather();
      buienradar();
    }

    if (millis() - time_4 >= 5000) {     // 5 seconden
      time_4 = millis();
      showRSSI();
      if (display_weather) {
        if (WiFi.status() != WL_CONNECTED) {
          if (wifistatus) {
            Serial.println("WiFi connection lost. Reconnecting...");
            wifistatus = false;
            WiFi.reconnect();
            Display.writeNum("rssi", 0);
          }
        } else if (!wifistatus) {
          Serial.println("WiFi verbonden");
          wifistatus = true;
        }
      }
      getIndoor();
      showData();
      showGPS();

      // Heap monitoring — herstart bij kritieke fragmentatie
      uint32_t largestBlock = heap_caps_get_largest_free_block(MALLOC_CAP_8BIT);
      if (largestBlock < 60000) {
        Serial.printf("Heap kritiek: grootste blok %d bytes, herstart!\n", largestBlock);
        ESP.restart();
      }
    }

    if (millis() - time_6 >= 600000) {   // 10 minuten
      time_6 = millis();
      beeper_lightning = false;
      if (!weeralarm) {
        Display.writeNum("b_alarm.pic", 67);
      }
    }

    if (millis() - time_5 >= 300000) {   // 5 minuten auto-dimmer
      if (autodim) Display.writeStr("dim=3");
      time_5 = millis();
    }

    if (weeralarm == 1 || alarmswitch == 0) {
      if (digitalRead(intPin) == HIGH) {
        byte x = lightning.readInterruptReg();

        if (x == 0x01) {
          Serial.println("Noise detected!");
        }

        if (x == 0x04) {
          Serial.println("Disturber detected!");
        }

        if (x == 0x08) {
          unsigned int lightningDistKm = lightning.distanceToStorm();
          Serial.println("Lightning occurs!");
          Serial.print("Distance: ");
          Serial.print(lightningDistKm);
          Serial.println(" km");

          unsigned int lightningEnergyVal = lightning.lightningEnergy();
          Serial.print("Intensity: ");
          Serial.print(lightningEnergyVal);
          Serial.println("");

          if (lightningDistKm > 1) {
            lightningcount++;
            if (!beeper_lightning) {
              buzzer(0);
              beeper_lightning = true;
              time_6 += 600000;
              Display.writeNum("b_alarm.pic", 49);
            }
            if (lightningcount > 5) {
              for (int i = 0; i < 5; i++) lightningtext[i] = lightningtext[i + 1];
              lightningtext[5] = (datetimestamp + " Afstand: " + String(lightningDistKm) + "km");
              lightningcount = 5;
            } else {
              lightningtext[lightningcount] = (datetimestamp + " Afstand: " + String(lightningDistKm) + "km");
            }
            lightningtextmerge = (lightningtext[0] + "\\r" + lightningtext[1] + "\\r" + lightningtext[2] + "\\r" + lightningtext[3] + "\\r" + lightningtext[4] + "\\r" + lightningtext[5] + "\\r");
          }
        }
      }
    }
  }

  digitalWrite(2, LOW);
}

void setLightning() {
  lightning.setMaskDisturber(true);
  if (indoor) lightning.setIndoorOutdoor(AS3935_INDOOR); else lightning.setIndoorOutdoor(AS3935_OUTDOOR);
  lightning.setNoiseLevel(2);
  lightning.setWatchdogThreshold(threshold);
  lightning.setSpikeRejection(spike);
  lightning.setLightningThreshold(1);

  Serial.println("Lightning watchdog threshold set to: " + String(lightning.readWatchdogThreshold()));
  Serial.println("Lightning spike rejection set to: " + String(lightning.readSpikeRejection()));
  Serial.println("Lightning threshold set to: " + String(lightning.readLightningThreshold()));
  Serial.println("Lightning noise level set to: " + String(lightning.readNoiseLevel()));
}

void trigger1() {   // Weather view
  if (currenttrigger != 1) {
    Display.writeNum("dim", contrast);
    time_5 = millis();
    ResetScreenData();
    display_weather = true;
    display_gps = false;
    display_radio = false;
    display_alarm = false;
    if (radio == 0) Display.writeNum("radiobutton", 0);
    if (radio == 1) Display.writeNum("radiobutton", 1);
    Display.writeStr("page 1");
    showData();
    currenttrigger = 1;
  }
}

void trigger2() {   // Radio view
  if (currenttrigger != 2) {
    Display.writeNum("dim", contrast);
    time_5 = millis();
    ResetScreenData();
    display_weather = false;
    display_radio = true;
    Display.writeStr("page 3");
    showData();
    currenttrigger = 2;
  }
}

void trigger3() {   // GPS view
  if (currenttrigger != 3) {
    Display.writeNum("dim", contrast);
    time_5 = millis();
    ResetScreenData();
    display_weather = false;
    display_gps = true;
    Display.writeStr("page 2");
    showData();
    showGPS();
    currenttrigger = 3;
  }
}

void trigger4() {   // Config1 view
  if (currenttrigger != 4) {
    menu = true;
    Display.writeNum("dim", contrast);
    time_5 = millis();
    ResetScreenData();
    display_weather = false;
    Display.writeStr("page 9");
    delay(100);
    if (!alarmswitch) {
      Display.writeNum("b_weeralarm.pic", 50);
    } else {
      Display.writeNum("b_weeralarm.pic", 51);
    }
    if (!indoor) {
      Display.writeNum("b_indoor.pic", 50);
    } else {
      Display.writeNum("b_indoor.pic", 51);
    }
    Display.writeNum("thresholdval.val", threshold);
    Display.writeNum("bliksemval.val", spike);
    Display.writeStr("api.txt", key);
    showData();
    currenttrigger = 4;
  }
}

void trigger5() {   // Config1 afsluiten
  if (currenttrigger != 5) {
    Display.writeNum("dim", contrast);
    time_5 = millis();
    delay(100);
    if (Display.readNumber("b_weeralarm.pic") == 50) {
      alarmswitch = false;
    } else {
      alarmswitch = true;
    }
    delay(100);
    if (Display.readNumber("b_indoor.pic") == 50) {
      indoor = false;
    } else {
      indoor = true;
    }
    delay(100);
    threshold = Display.readNumber("thresholdval.val");
    delay(100);
    spike = Display.readNumber("bliksemval.val");
    EEPROM.writeByte(39, alarmswitch);
    EEPROM.writeByte(34, indoor);
    EEPROM.writeByte(35, threshold);
    EEPROM.writeByte(38, spike);
    EEPROM.commit();

    Display.writeStr("page 4");
    delay(100);
    ResetScreenData();
    if (!beeper) {
      Display.writeNum("b_beeper.pic", 50);
    } else {
      Display.writeNum("b_beeper.pic", 51);
    }
    if (!radio) {
      Display.writeNum("b_radio.pic", 50);
    } else {
      Display.writeNum("b_radio.pic", 51);
    }
    if (!kmu) {
      Display.writeNum("kmu.pic", 50);
    } else {
      Display.writeNum("kmu.pic", 51);
    }
    Display.writeNum("contrastval.val", contrast);
    Display.writeStr("api.txt", key);
    showData();
    currenttrigger = 5;
  }
}

void trigger6() {    // Update locatie
  Display.writeNum("dim", contrast);
  time_5 = millis();
  if (Display.readNumber("b_radio.pic") == 50) {
    radio = false;
  } else {
    radio = true;
  }
  ResetScreenData();
  showData();
}

void trigger7() {   // WiFi configuratiescherm
  if (currenttrigger != 7) {
    Display.writeNum("dim", contrast);
    time_5 = millis();
    Display.writeStr("page 5");
    Display.writeStr("qr.txt", (String("WIFI:T:nopass;S:ESP_" + String(ESP_getChipId()) + ";P:;H:;")));
    Display.writeStr("SSID_AP.txt", (String("ESP_" + String(ESP_getChipId()))));
    setWifi();
    ESP.restart();
    currenttrigger = 7;
  }
}

void trigger8() {   // WiFi retry
  if (currenttrigger != 8) {
    if (wc.autoConnect()) {
      wifistatus = true;
    } else {
      Display.writeStr("page 6");
    }
    currenttrigger = 8;
  }
}

void trigger9() {   // Warning view
  if (currenttrigger != 9) {
    Display.writeNum("dim", contrast);
    time_5 = millis();
    ResetScreenData();
    display_weather = false;
    display_alarm = true;
    Display.writeStr("page 7");
    Display.writeStr("warning.txt", alarmtxt);
    showData();
    currenttrigger = 9;
  }
}

void trigger10() {   // Warning afsluiten
  if (currenttrigger != 10) {
    currenttrigger = 10;
    trigger1();
  }
}

void trigger11() {  // Config 3 afsluiten
  if (currenttrigger != 11) {
    Display.writeNum("dim", contrast);
    time_5 = millis();
    delay(100);
    if (Display.readNumber("b_autoloc.pic") == 50) {
      autoloc = false;
    } else {
      autoloc = true;
    }
    delay(100);
    if (Display.readNumber("b_ntp.pic") == 50) {
      ntp = false;
    } else {
      ntp = true;
    }
    delay(100);
    if (Display.readNumber("b_dimmer.pic") == 50) {
      autodim = false;
    } else {
      autodim = true;
    }
    delay(100);
    indooroffset = Display.readNumber("indooroffset.val");
    EEPROM.writeByte(33, autoloc);
    EEPROM.writeByte(40, ntp);
    EEPROM.writeInt(42, indooroffset);
    EEPROM.writeByte(36, autodim);
    EEPROM.commit();
    currenttrigger = 11;
    menu = false;
    setLightning();
    trigger1();
  }
}

void trigger12() {
  Display.writeNum("dim", contrast);
  time_5 = millis();
}

void trigger13() {
  buzzer(1);
}

void trigger14() {  // Config 2 afsluiten
  if (currenttrigger != 14) {
    Display.writeNum("dim", contrast);
    time_5 = millis();
    delay(100);
    if (Display.readNumber("b_beeper.pic") == 50) {
      beeper = false;
    } else {
      beeper = true;
    }
    delay(100);
    if (Display.readNumber("b_radio.pic") == 50) {
      radio = false;
    } else {
      radio = true;
    }
    delay(100);
    if (Display.readNumber("kmu.pic") == 50) {
      kmu = false;
    } else {
      kmu = true;
    }
    delay(100);
    contrast = Display.readNumber("contrastval.val");
    EEPROM.writeByte(29, beeper);
    EEPROM.writeByte(30, radio);
    EEPROM.writeByte(32, kmu);
    EEPROM.writeByte(37, contrast);
    EEPROM.commit();
    Display.writeNum("setkmu", kmu);
    delay(100);
    Display.writeStr("page 8");
    delay(100);
    ResetScreenData();
    if (!autoloc) {
      Display.writeNum("b_autoloc.pic", 50);
    } else {
      Display.writeNum("b_autoloc.pic", 51);
    }
    if (!ntp) {
      Display.writeNum("b_ntp.pic", 50);
    } else {
      Display.writeNum("b_ntp.pic", 51);
    }
    if (!autodim) {
      Display.writeNum("b_dimmer.pic", 50);
    } else {
      Display.writeNum("b_dimmer.pic", 51);
    }
    Display.writeNum("indooroffset.val", indooroffset);
    Display.writeStr("api.txt", key);
    showData();
    currenttrigger = 5;
  }
}

void ResetScreenData() {
  lightningtextmergeold = " ";
  dayname1old = " ";
  dayname2old = " ";
  longitudeold = " ";
  latitudeold = " ";
  datetimeold = " ";
  qthold = " ";
  muf_stringold[0] = " ";
  muf_stringold[1] = " ";
  muf_stringold[2] = " ";
  muf_stringold[3] = " ";
  muf_stringold[4] = " ";
  muf_stringold[5] = " ";
  muf_stringold[6] = " ";
  muf_stringold[7] = " ";
  muf_stringold[8] = " ";
  solarfluxold = " ";
  aindexold = " ";
  kindexold = " ";
  sunspotsold = " ";
  protonfluxold = " ";
  electonfluxold = " ";
  zonopold = " ";
  zononderold = " ";
  auroraold = " ";
  normalisationold = " ";
  latdegreeold = " ";
  solarwindold = " ";
  magneticfieldold = " ";
  d8040mold = " ";
  n8040mold = " ";
  d3020mold = " ";
  n3020mold = " ";
  d1715mold = " ";
  n1715mold = " ";
  d1210mold = " ";
  n1210mold = " ";
  es2mold = " ";
  es6mold = " ";
  es4mold = " ";
  geomagfieldold = " ";
  signalnoiseold = " ";
  plaatsold = " ";
  windkmhold = 0;
  windmsold = 0;
  tempold = 0;
  samenvold = " ";
  lvold = 0;
  dauwold = 0;
  windrold = " ";
  windsold = 0;
  luchtdold = 0;
  zichtold = 0;
  verwold = " ";
  imageold = 0;
  weeralarmold = 0;
  d1imageold = 0;
  d2imageold = 0;
  d1zonold = 0;
  d1neerslagold = 0;
  d2zonold = 0;
  d2neerslagold = 0;
  d0tminold = 0;
  d0tmaxold = 0;
  d1tminold = 0;
  d1tmaxold = 0;
  d1windkold = 0;
  d1windrold = " ";
  d2tminold = 0;
  d2tmaxold = 0;
  d2windkold = 0;
  d2windrold = " ";
  indoorhumold = 0;
  indoortempold = 0;
  indoorvocold = 0;
  weeralarmold = false;
  weercodeold = " ";
  br_tijdold = " ";
}

void showRSSI()
{
  long rssi = WiFi.RSSI();
  if (rssi != rssiold) {
    rssiold = rssi;
    byte level;
    if (rssi == 0)        level = 0;
    else if (rssi > -50)  level = 4;
    else if (rssi > -60)  level = 3;
    else if (rssi > -70)  level = 2;
    else                  level = 1;
    Display.writeNum("rssi", level);
  }
}

void setWifi() {
  char api_key [11];
  key.toCharArray(api_key, 11);
  WiFiConnectParam api_key_text("Enter weerlive.nl API key:");
  WiFiConnectParam api_key_input("api_key", "API Key", api_key, 11);
  wc.addParameter(&api_key_text);
  wc.addParameter(&api_key_input);

  wc.startConfigurationPortal();
  Serial.println("Ontvangen waarde: ");
  Serial.println(api_key_input.getValue());
  EEPROM.writeString(17, String(api_key_input.getValue()));
  EEPROM.commit();
  key = String(api_key_input.getValue());
  if (!wc.autoConnect()) {
    Serial.println("Geen verbinding, opnieuw instellen");
  }
}
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

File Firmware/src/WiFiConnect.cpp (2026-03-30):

/*!
   @file WiFiConnect.cpp

   WiFi connection manager for ESP32 with captive portal.
   Based on WiFiConnect by Stuart Blair, derived from WiFiManager by tzapu.

   GNU General Public License v3.0
*/
#include "WiFiConnect.h"

// ---- CSS ----

static const char TPL_STYLE[] PROGMEM =
  "<style>"
  "*{margin:0;padding:0;box-sizing:border-box}"
  "body{font-family:-apple-system,'Segoe UI',system-ui,sans-serif;background:#202228;color:#fff;min-height:100vh}"
  ".w{max-width:440px;margin:0 auto;padding:20px 16px}"
  "h1{color:#5bd6ab;font-size:.92em;font-weight:600;text-transform:uppercase;letter-spacing:3px;"
    "text-align:center;padding-bottom:12px;margin-bottom:18px;border-bottom:1px solid rgba(91,214,171,.15)}"
  ".msg{background:rgba(46,80,73,.3);border:1px solid rgba(60,127,106,.2);border-radius:12px;"
    "padding:14px 18px;font-size:.88em;color:#a0a8b0;line-height:1.6;margin-bottom:20px;text-align:center}"
  ".cd{background:rgba(46,80,73,.12);border:1px solid rgba(60,127,106,.18);border-radius:14px;"
    "padding:16px;margin-bottom:14px}"
  ".cd h2{font-size:.7em;color:#4db691;text-transform:uppercase;letter-spacing:1.5px;"
    "margin-bottom:12px;font-weight:600;padding-left:10px;border-left:3px solid #4db691}"
  "button,input[type=submit]{display:block;width:100%;padding:14px;background:#4db691;"
    "color:#1a1c20;border:0;border-radius:12px;font-size:.92em;font-weight:600;"
    "font-family:inherit;text-transform:uppercase;letter-spacing:.5px;cursor:pointer;"
    "margin-bottom:8px;transition:background .2s}"
  "button:hover{background:#5bd6ab}"
  ".alt{background:0 0;color:#8090a0;border:1px solid rgba(60,127,106,.3);"
    "text-transform:none;font-weight:400;font-size:.82em;letter-spacing:0;padding:10px}"
  ".alt:hover{background:rgba(46,80,73,.2);color:#c0c8d0;border-color:#3c7f6a}"
  "label{display:block;font-size:.7em;color:#6a7280;text-transform:uppercase;"
    "letter-spacing:1px;margin:8px 0 4px;font-weight:500}"
  "input[type=text],input[type=password]{display:block;width:100%;padding:11px 14px;"
    "background:rgba(20,22,26,.5);border:1px solid rgba(60,127,106,.22);border-radius:10px;"
    "color:#e0e4e8;font-size:.9em;font-family:inherit;margin-bottom:10px;outline:0;"
    "transition:border .2s;-webkit-appearance:none}"
  "input[type=text]:focus,input[type=password]:focus{border-color:#5bd6ab}"
  "input::placeholder{color:#3a4250}"
  ".n{background:rgba(20,22,26,.35);border:1px solid rgba(60,127,106,.12);"
    "border-radius:10px;padding:10px 12px;margin-bottom:5px;cursor:pointer;"
    "display:flex;align-items:center;gap:10px;transition:border .2s}"
  ".n:hover{border-color:#3c7f6a}.n:active{border-color:#5bd6ab}"
  ".n span:first-child{color:#d0d4d8;flex:1;overflow:hidden;text-overflow:ellipsis;"
    "white-space:nowrap;font-size:.88em}"
  ".q{display:flex;align-items:center;gap:5px;font-size:.72em;color:#505868;"
    "font-family:ui-monospace,monospace;white-space:nowrap}"
  ".sig{display:flex;align-items:flex-end;gap:1px;height:12px}"
  ".sig i{display:block;width:3px;background:#1a2a24;border-radius:1px}"
  ".sig i:nth-child(1){height:3px}.sig i:nth-child(2){height:6px}"
  ".sig i:nth-child(3){height:9px}.sig i:nth-child(4){height:12px}"
  ".s1 i:nth-child(1){background:#f85149}"
  ".s2 i:nth-child(-n+2){background:#e8a838}"
  ".s3 i:nth-child(-n+3){background:#4db691}"
  ".s4 i{background:#5bd6ab}"
  ".lk{font-size:.55em;color:#505868;margin-left:1px}.lk::after{content:'\\1F512'}"
  ".ok,.fail{text-align:center;padding:18px;border-radius:14px;margin-top:16px;"
    "display:none;line-height:1.6}"
  ".ok{background:rgba(46,80,73,.3);border:1px solid rgba(60,127,106,.2);color:#5bd6ab}"
  ".fail{background:rgba(74,32,32,.3);border:1px solid rgba(106,48,48,.2);color:#f85149}"
  ".fail a{color:#f85149}"
  ".ld::after{content:'';display:inline-block;width:22px;height:22px;"
    "border:2px solid rgba(60,127,106,.2);border-top-color:#5bd6ab;"
    "border-radius:50%;animation:r .7s linear infinite}"
  "@keyframes r{to{transform:rotate(360deg)}}"
  ".ldw{text-align:center;padding:24px 0}"
  ".pt{color:#6a7280;font-size:.8em;margin:10px 0 2px;padding-top:8px;"
    "border-top:1px solid rgba(60,127,106,.1)}"
  ".pw{position:relative}"
  ".pw input{padding-right:44px}"
  ".pw button{position:absolute;right:3px;top:3px;width:36px;height:calc(100% - 16px);"
    "background:rgba(46,80,73,.3);border:0;border-radius:8px;padding:0;margin:0;"
    "color:#506070;cursor:pointer;display:flex;align-items:center;justify-content:center;"
    "text-transform:none;letter-spacing:0;font-size:.8em}"
  ".pw button:hover{color:#5bd6ab;background:rgba(46,80,73,.5)}"
  ".pw svg{width:16px;height:16px;fill:none;stroke:currentColor;stroke-width:1.5;"
    "stroke-linecap:round;stroke-linejoin:round}"
  ".hn{display:flex;align-items:center;gap:8px;font-size:.8em;color:#506070;"
    "margin:0 0 12px;cursor:pointer;font-weight:400;text-transform:none;letter-spacing:0}"
  ".hn input{width:auto;margin:0;accent-color:#4db691;-webkit-appearance:auto;appearance:auto}"
  "</style>";

// ---- JavaScript ----

static const char TPL_WIFI_JS[] PROGMEM =
  "function scan(){"
    "var nl=document.getElementById('nl');"
    "nl.innerHTML='<div class=\"ldw\"><span class=\"ld\"></span></div>';"
    "var x=new XMLHttpRequest;"
    "x.onload=function(){"
      "try{var d=JSON.parse(x.responseText);var h='';"
      "for(var i=0;i<d.n.length;i++){var n=d.n[i];"
        "var sl=n.r<26?'s1':n.r<51?'s2':n.r<76?'s3':'s4';"
        "h+='<div class=\"n\" onclick=\"sel(this)\"><span>'+esc(n.s)+'</span>'"
        "+'<span class=\"q\"><span class=\"sig '+sl+'\"><i></i><i></i><i></i><i></i></span>'"
        "+(n.e?'<span class=\"lk\"></span>':'')+'</span></div>';}"
      "nl.innerHTML=h||'<div class=\"msg\">Geen netwerken gevonden</div>';"
      "}catch(e){nl.innerHTML='<div class=\"msg\">Geen netwerken gevonden</div>';}};"
    "x.onerror=function(){nl.innerHTML='<div class=\"msg\">Geen netwerken gevonden</div>';};"
    "x.open('GET','/scan');x.send();}"
  "function esc(s){var d=document.createElement('div');"
    "d.appendChild(document.createTextNode(s));return d.innerHTML;}"
  "function sel(el){"
    "var s=el.querySelector('span').textContent;"
    "document.getElementById('s').value=s;"
    "document.getElementById('hn').checked=false;"
    "document.getElementById('p').focus();}"
  "function togglePw(){"
    "var p=document.getElementById('p');"
    "p.type=p.type==='password'?'text':'password';}"
  "function toggleHn(){"
    "var c=document.getElementById('hn').checked;"
    "var s=document.getElementById('s');"
    "if(c){s.value='';s.focus();}}"
  "window.addEventListener('load',scan);";

// ---- WiFiConnectParam ----

WiFiConnectParam::WiFiConnectParam(const char *custom) {
  _id = NULL; _placeholder = NULL; _length = 0; _value = NULL; _customHTML = custom;
}
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

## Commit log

2023-06-28 Update Github layout
    [Weerstation-B_Cu.gbr, Weerstation-B_Mask.gbr, Weerstation-B_Paste.gbr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]
2023-10-05 Versie 1.2
    - Radiobutton was altijd zichtbaar, ook al was deze in het menu uitgeschakeld
    - Dauwpunt toegevoegd aan weer-pagina
    - Tickers (scrollende teksten) zijn nu vloeiender
    - Datum/tijd weergave heeft nu een paar pixels meer ruimte.
2023-10-05 Update naar v1.2
    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
2026-03-30 Bugfix in weerbericht parser
    Migratie naar Platformio
    [Firmware.ino]
